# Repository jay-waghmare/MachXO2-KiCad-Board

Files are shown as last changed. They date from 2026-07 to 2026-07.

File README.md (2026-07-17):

# MachXO2-640HC FPGA Breakout Board - KiCad Design 🛠️

> Custom breakout board for Lattice **LCMXO2-640HC-6MG132I** - Designed in KiCad 9.0.3 - 8 Sheets Hierarchical - By Jay Waghmare






<p align="center">
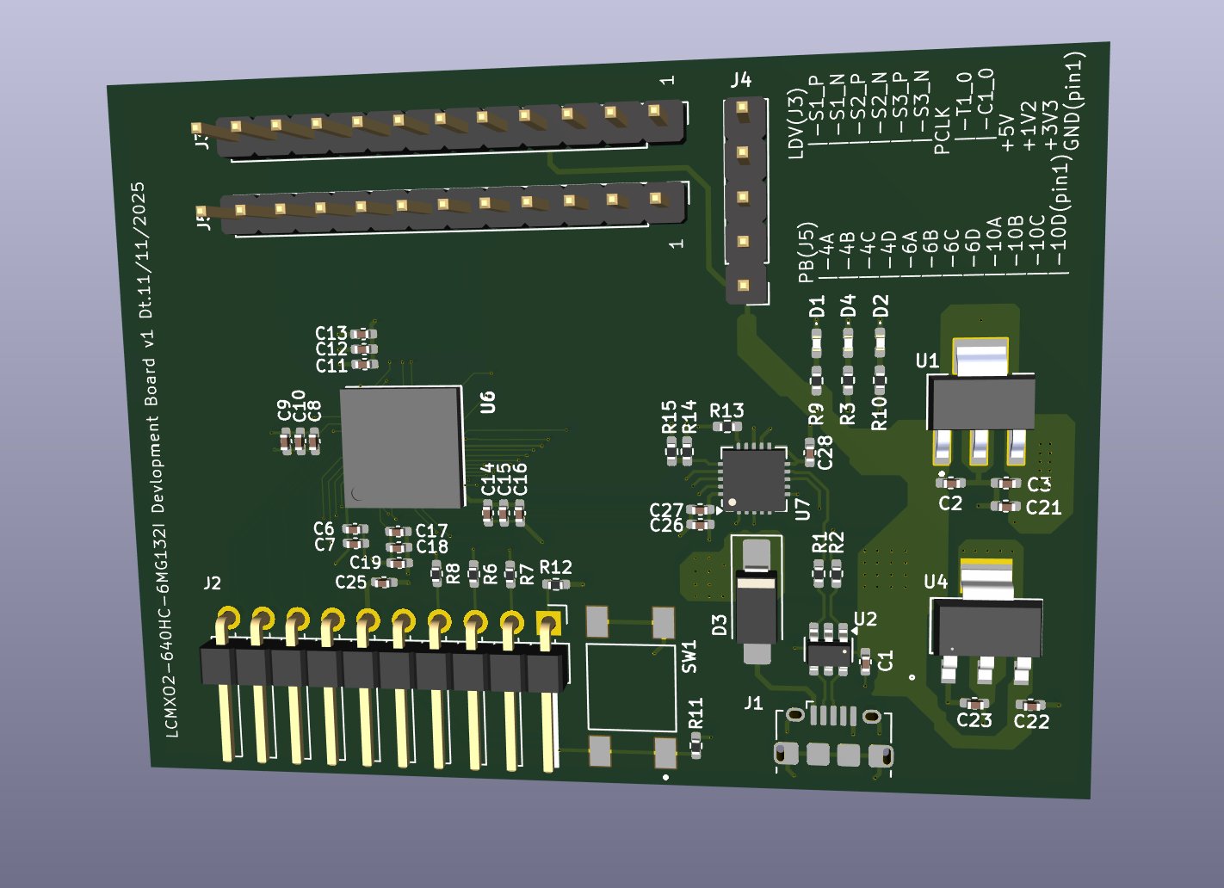
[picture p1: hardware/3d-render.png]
3D Render
  
  <br><em>3D Render - MachXO2-640HC Board (KiCad 3D View)</em>
</p>

## 🌟 What Is This? (From My Schematic PDF)

Custom FPGA development board designed from scratch in KiCad for **Lattice MachXO2 LCMXO2-640HC-6MG132I** (640 LUTs, 132-ball CSBGA).

**Full breakout board, not simple LED:**

- USB Mini-B (J1) for power + data with ESD protection USBLC6-2SC6 (U2)
- Dual LDO: 5V→3.3V TL1963A-33DCYR (U4) and 5V→1.2V LD1117S12CTR (U5) for core + I/O
- FT231XQ USB-UART bridge (U7) for serial
- JTAG header 1x10 (J2) for Lattice HW-USBN-2B programmer (10 flywires - White TCK, Orange TDI, Brown TDO, Purple TMS...)
- All 4 I/O Banks broken out: Bank0 Top (PT6A...), Bank1 Right (PR28... LVDS), Bank2/3 Left (PL2A...), Bank Bottom (PB4A...) + GND/NC
- Power LEDs D1 D2, User LEDs, Button SW1 for PROGRAMN

Why I made my own? To learn FPGA hardware - Power sequencing, decoupling, JTAG, I/O banks.

**8 Sheets Hierarchical (KiCad 9.0.3, file MACHXO2_test.kicad_sch):**

| Sheet | File | Content |
|---|---|---|
| 1/8 | MACHXO2_test.kicad_sch | Top Level - Power, User_IO/Banks, Device_Management blocks |
| 2/8 | Power.kicad_sch | Power: USB Mini, 3.3V/1.2V LDOs, FPGA VCC/VCCIO decoupling C6 0.1uF C7 4.7uF etc, VCCIO table |
| 3/8 | USER_IO_Bank_T | Bank0 Top - U6B LCMXO2 Bank0, JTAG TDO/TDI/TCK/TMS, J3 12-pin socket |
| 4/8 | USER_IO_Bank_R | Bank1 Right - U6C Bank1, LVDS1/2/3, PCLK, J4 10-pin header |
| 5/8 | USER_IO_Bank_L | Bank Left - U6D Bank Left PL2A...PL7B |
| 6/8 | USER_IO_Bank_B | Bank Bottom - U6E Bank Bottom PB4A...PB14B |
| 7/8 | USER_Config | Config - JTAG J2, PROGRAMN button SW1, FT231XQ UART, JTAG header flywire table |
| 8/8 | GND&NC | GND & NC - U6F/U6G NC pins and GND balls |

## ✨ Board Features (From Schematic)

- **FPGA:** U6 LCMXO2-640HC-6MG132I, 640 LUTs, MG132I, Speed 6
- **Power:** J1 USB Mini-B, D3 1N5819HW?, U2 USBLC6-2SC6 ESD, U4 TL1963A-33DCYR 5V→3.3V (C2 4.7uF, C3 10uF, C21 10uF), U5 LD1117S12CTR 5V→1.2V (C22 4.7uF, C23 10uF, C24 10uF), D1 D2 power LEDs with R8 1K, C6 0.1uF C7 4.7uF per +1V2, C8 0.1uF C10 1uF C9 4.7uF per +3V3 bank - Proper decoupling!
- **Recommended VCCIO (Your Table):** PB left 3.3V (sensors, SPI flash), PL lower 1.8V (low-voltage memory), PR right 1.8V/2.5V (high-speed), PT top 3.3V (UART, SPI, USB-UART)
- **JTAG:** J2 1x10 header, R6 R7 R8 22R series for TDO/TDI/TCK/TMS, R11 4K7 pull-up for PROGRAMN, SW1 dual push button, Notes: INITN B13 open-drain float OK, JTAGENB B9 float OK (internal weak pull-up)
- **UART:** U7 FT231XQ with C26 4.7uF C27 0.1uF C28 0.1uF, TXD_FTDI, RXD_FTDI, RTS_FTDI, CTS, VBUS detection R1 4K7 + R13 10K divider
- **JTAG Programmer:** Lattice HW-USBN-2B USB cable with 10 flywire - Official tool - TCK White 4.7K to GND, TDI Orange 22R series, TDO Brown direct, TMS Purple 22R series, GND Black, VCC Red 0.1uF, PROGRAMN Yellow 4.7K+btn, DONE Blue LED+330Ω, INITN Green float, JTAGENB Gray float

## 📁 Files (Your Actual Uploads - Live)

**You uploaded:** .kicad_pro, .kicad_sch, .kicad_pcb, .kicad_prl, schematic.pdf, 3d-render.png, pcb_preview.png - Full project!

## 📸 Photos / Renders

| Schematic PDF | PCB Preview | 3D Render |
|---|---|---|
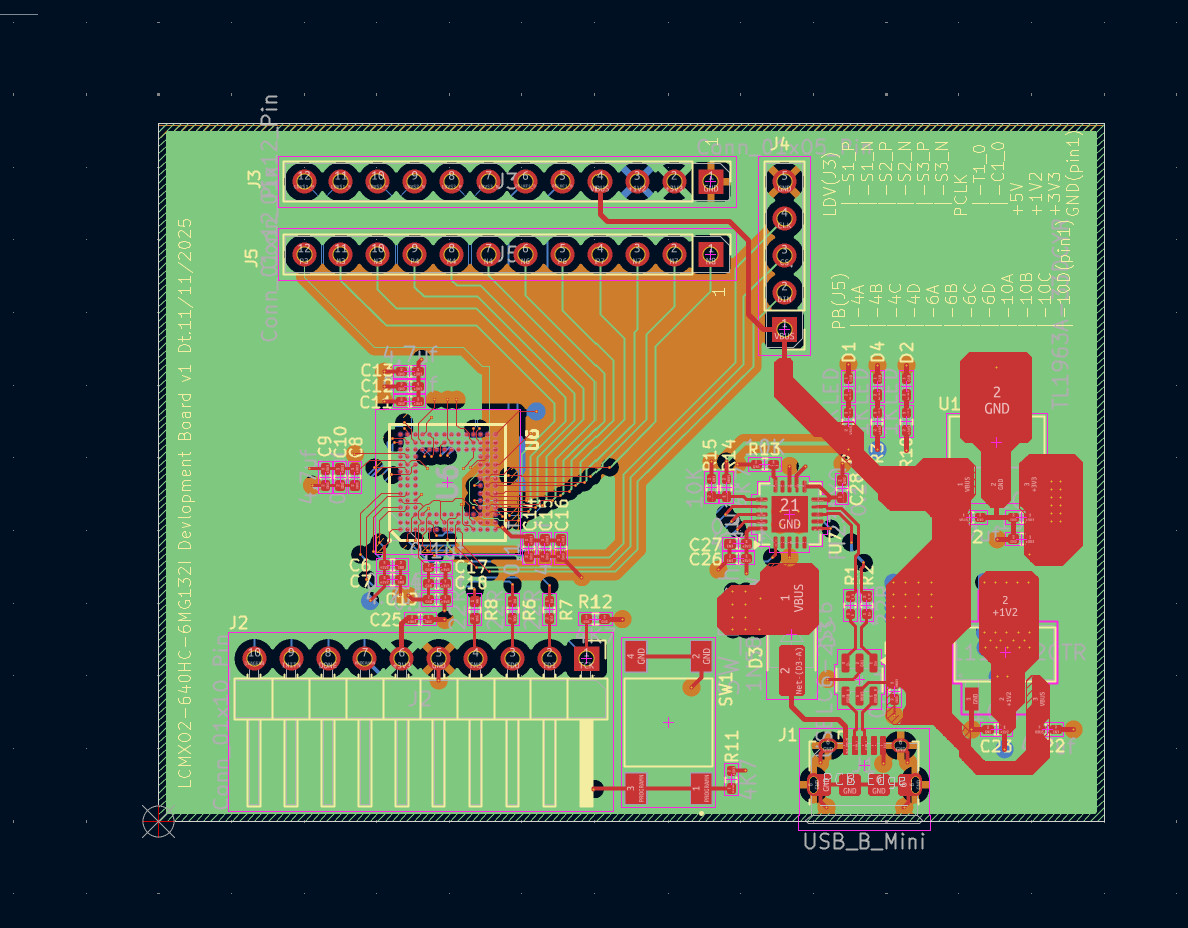
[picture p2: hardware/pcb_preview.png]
| [schematic.pdf](hardware/schematics/schematic.pdf) (8 pages) |  |  |

<p align="center">
  PCB Preview
  3D Render
</p>

## 📦 How to View

1. Install KiCad 9.0.3: https://kicad.org/download/
2. Clone: git clone https://github.com/jay-waghmare/MachXO2-KiCad-Board.git
cd MachXO2-KiCad-Board
3. Open `MACHXO2_test.kicad_pro` → Schematic Editor (8 sheets) → PCB Editor → 3D View

## 🗺️ Roadmap

- [x] KiCad hierarchical schematic 8 sheets - LCMXO2-640HC - Done (your PDF)
- [x] Upload .kicad_pro, .kicad_sch, .kicad_pcb, .kicad_prl - Done (5-6 greens today!)
- [x] Upload schematic.pdf + 3D renders - Done 5 mins ago!
- [ ] Add hardware/bom.md with exact values from schematic
- [ ] Add docs/design.md - Why 640HC, why TL1963A + LD1117, why 132-ball
- [ ] Export Gerbers: File → Fabrication Outputs → Gerbers → hardware/pcb/gerbers.zip
- [ ] Fabricate at JLCPCB
- [ ] Bring-up: Power test 3.3V/1.2V, JTAG scan with HW-USBN-2B, first blinky
- [ ] Add real board photos

## 👨‍💻 Author

**Jay Waghmare** - FPGA 
- GitHub: [@jay-waghmare](https://github.com/jay-waghmare) 
- Board: LCMXO2-640HC-6MG132I custom breakout - Designed from scratch in KiCad 9.0.3

If you like FPGA hardware boards, please ⭐ star!

## 📄 License

MIT License

> Designed from scratch in KiCad 9.0.3

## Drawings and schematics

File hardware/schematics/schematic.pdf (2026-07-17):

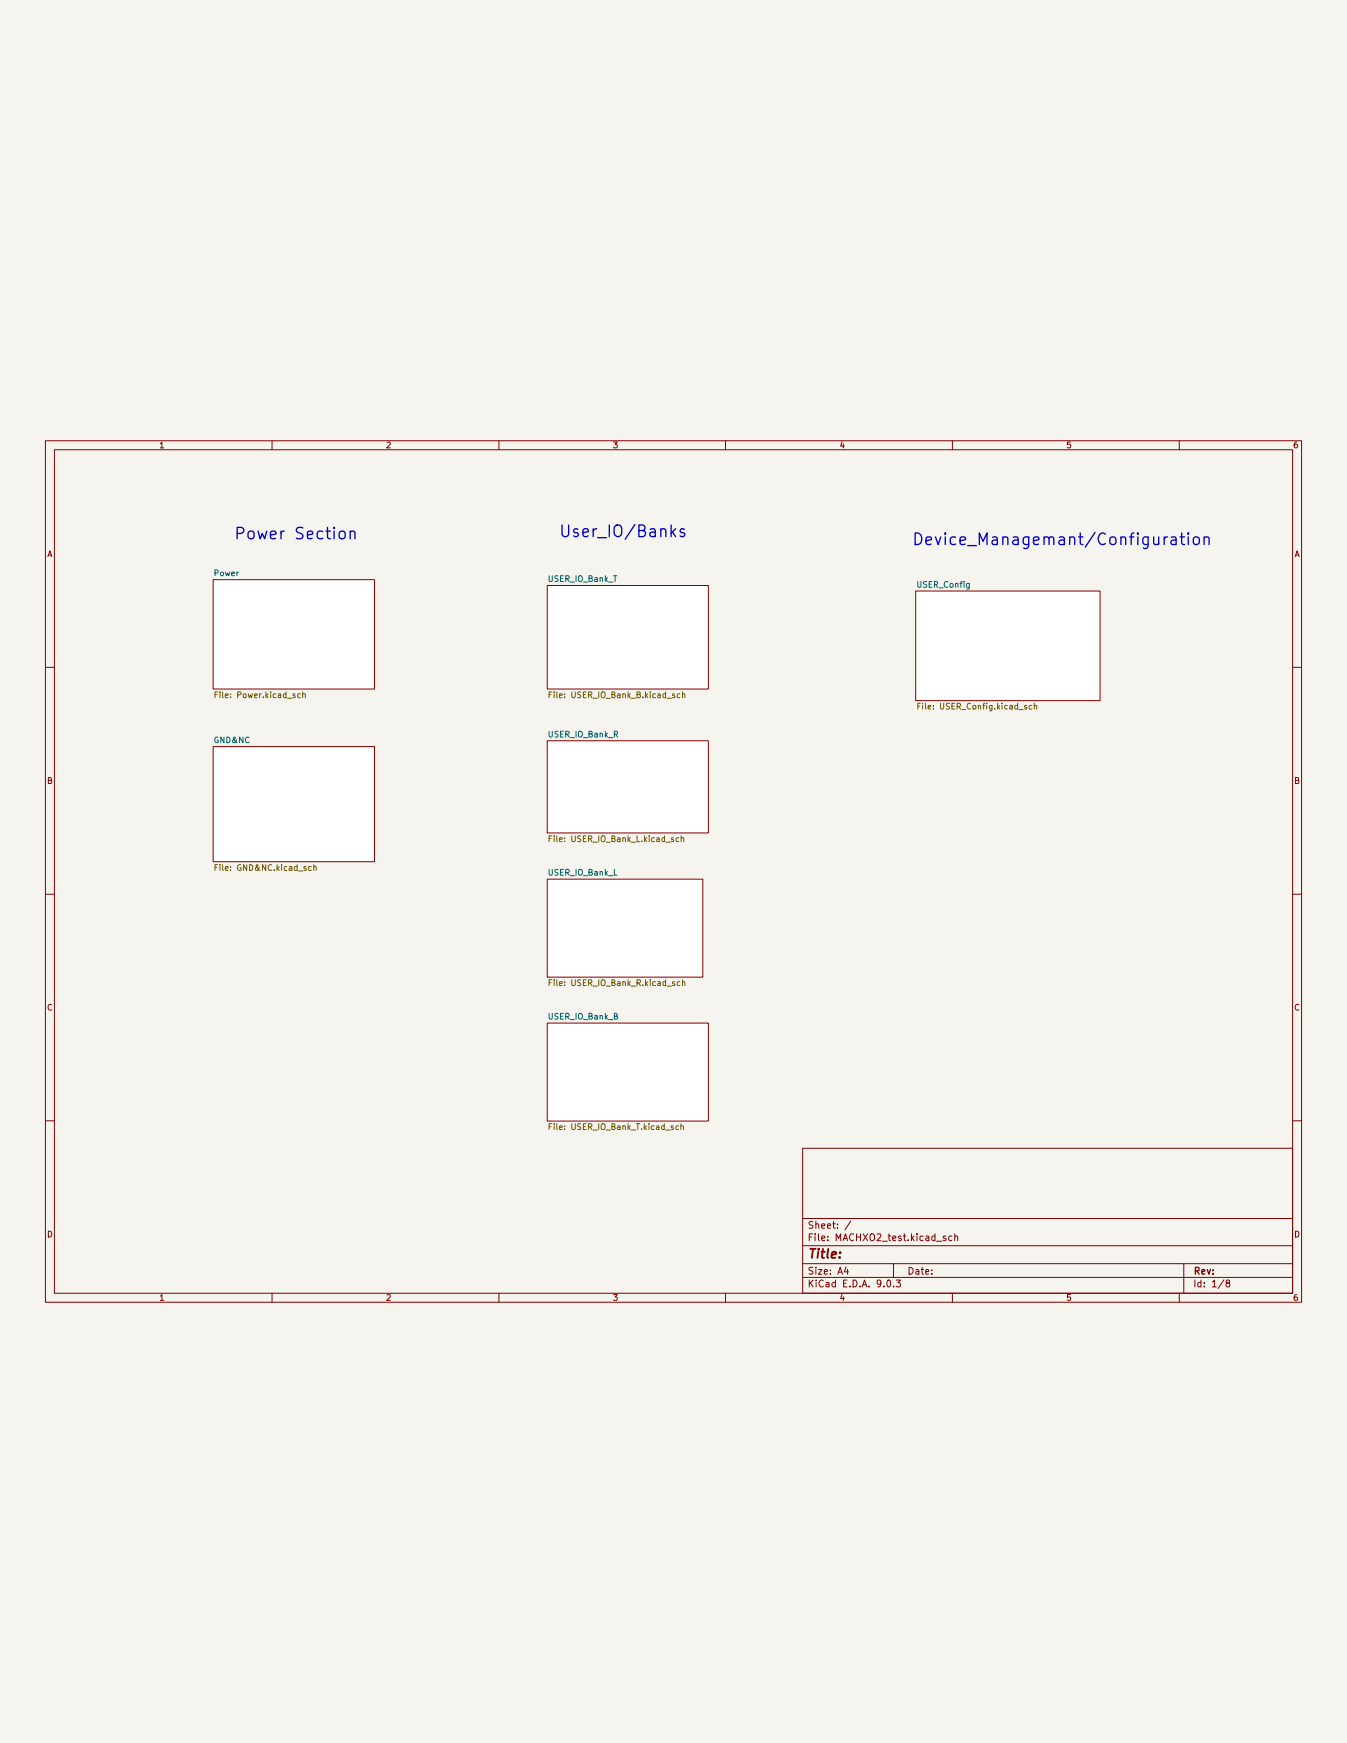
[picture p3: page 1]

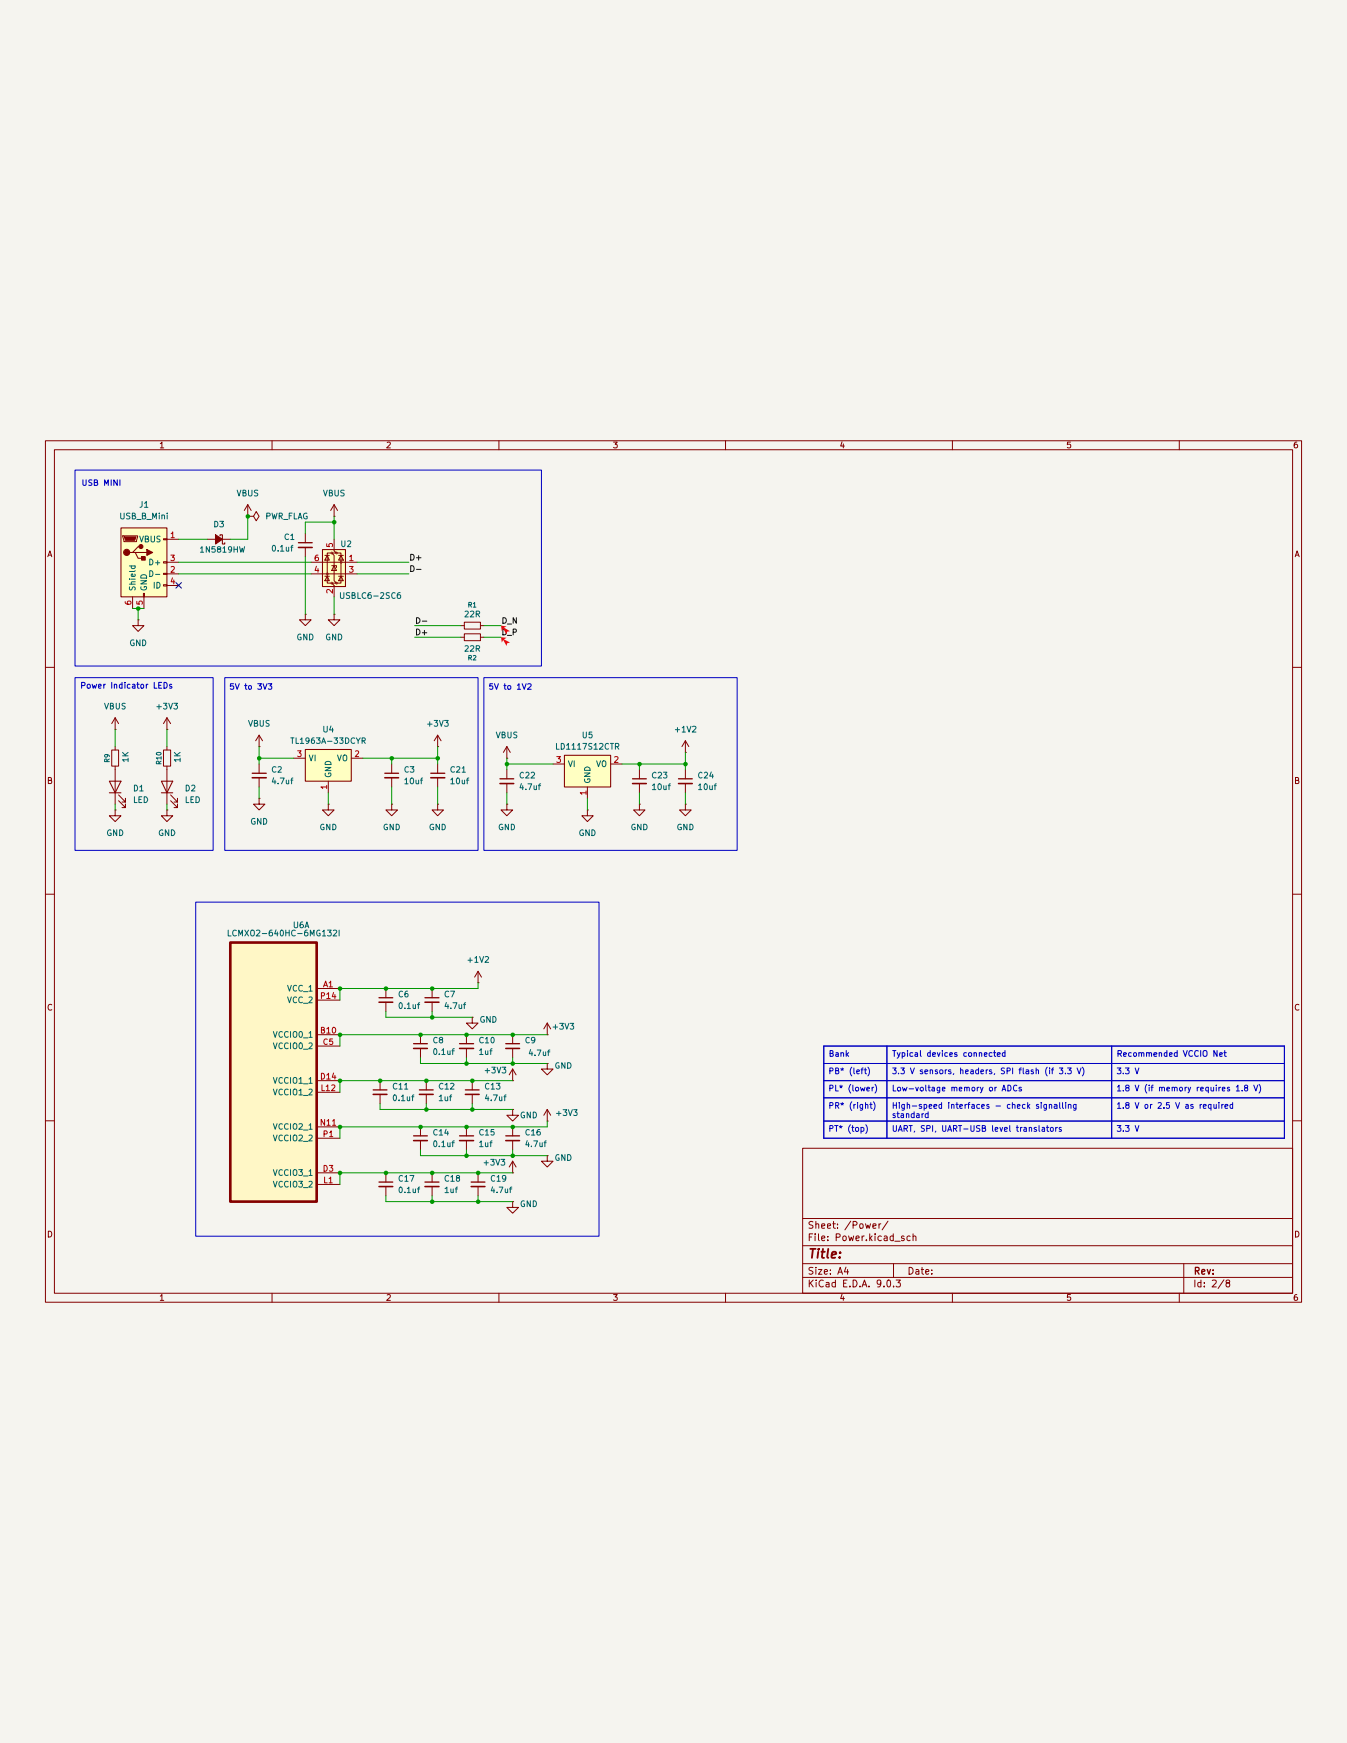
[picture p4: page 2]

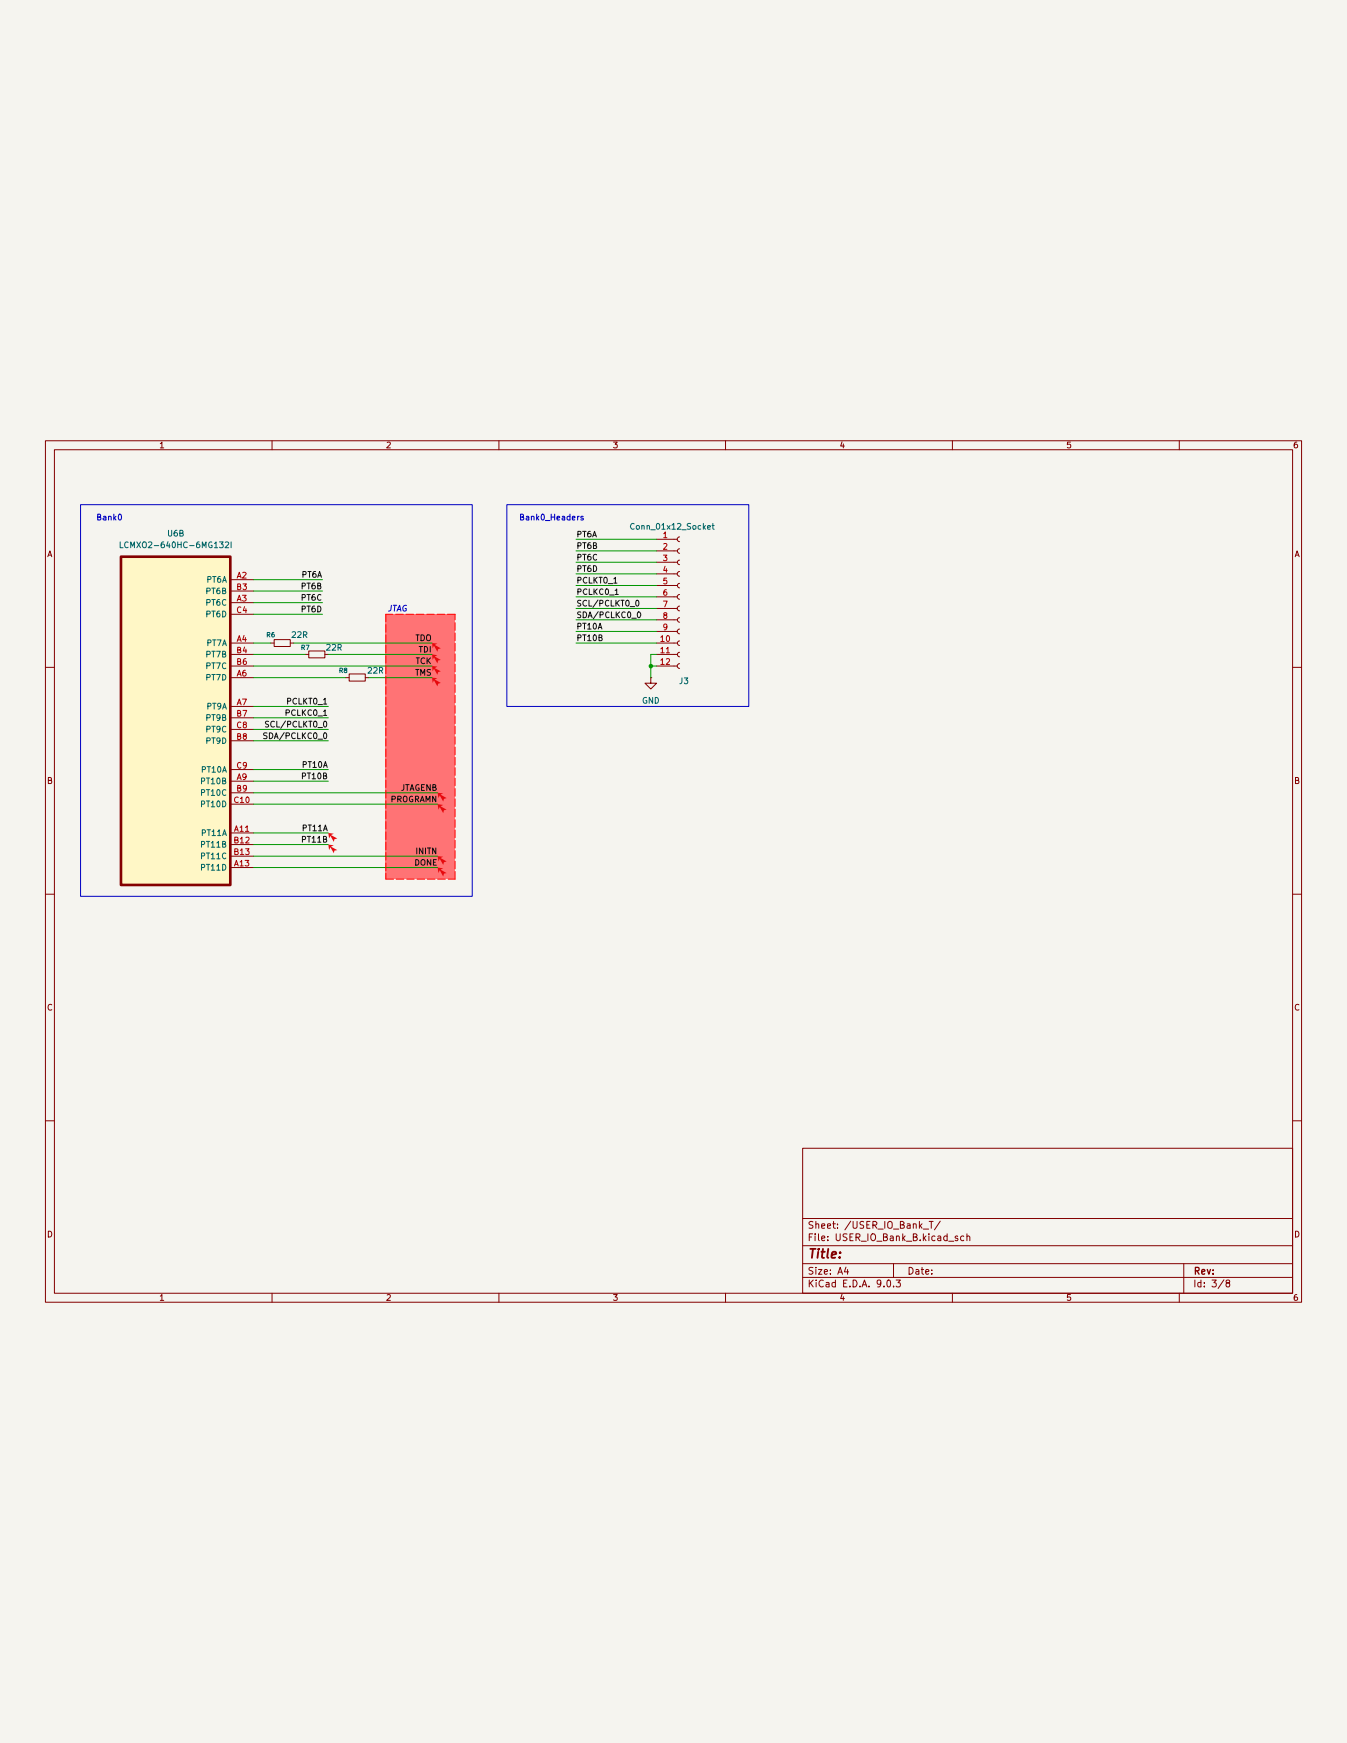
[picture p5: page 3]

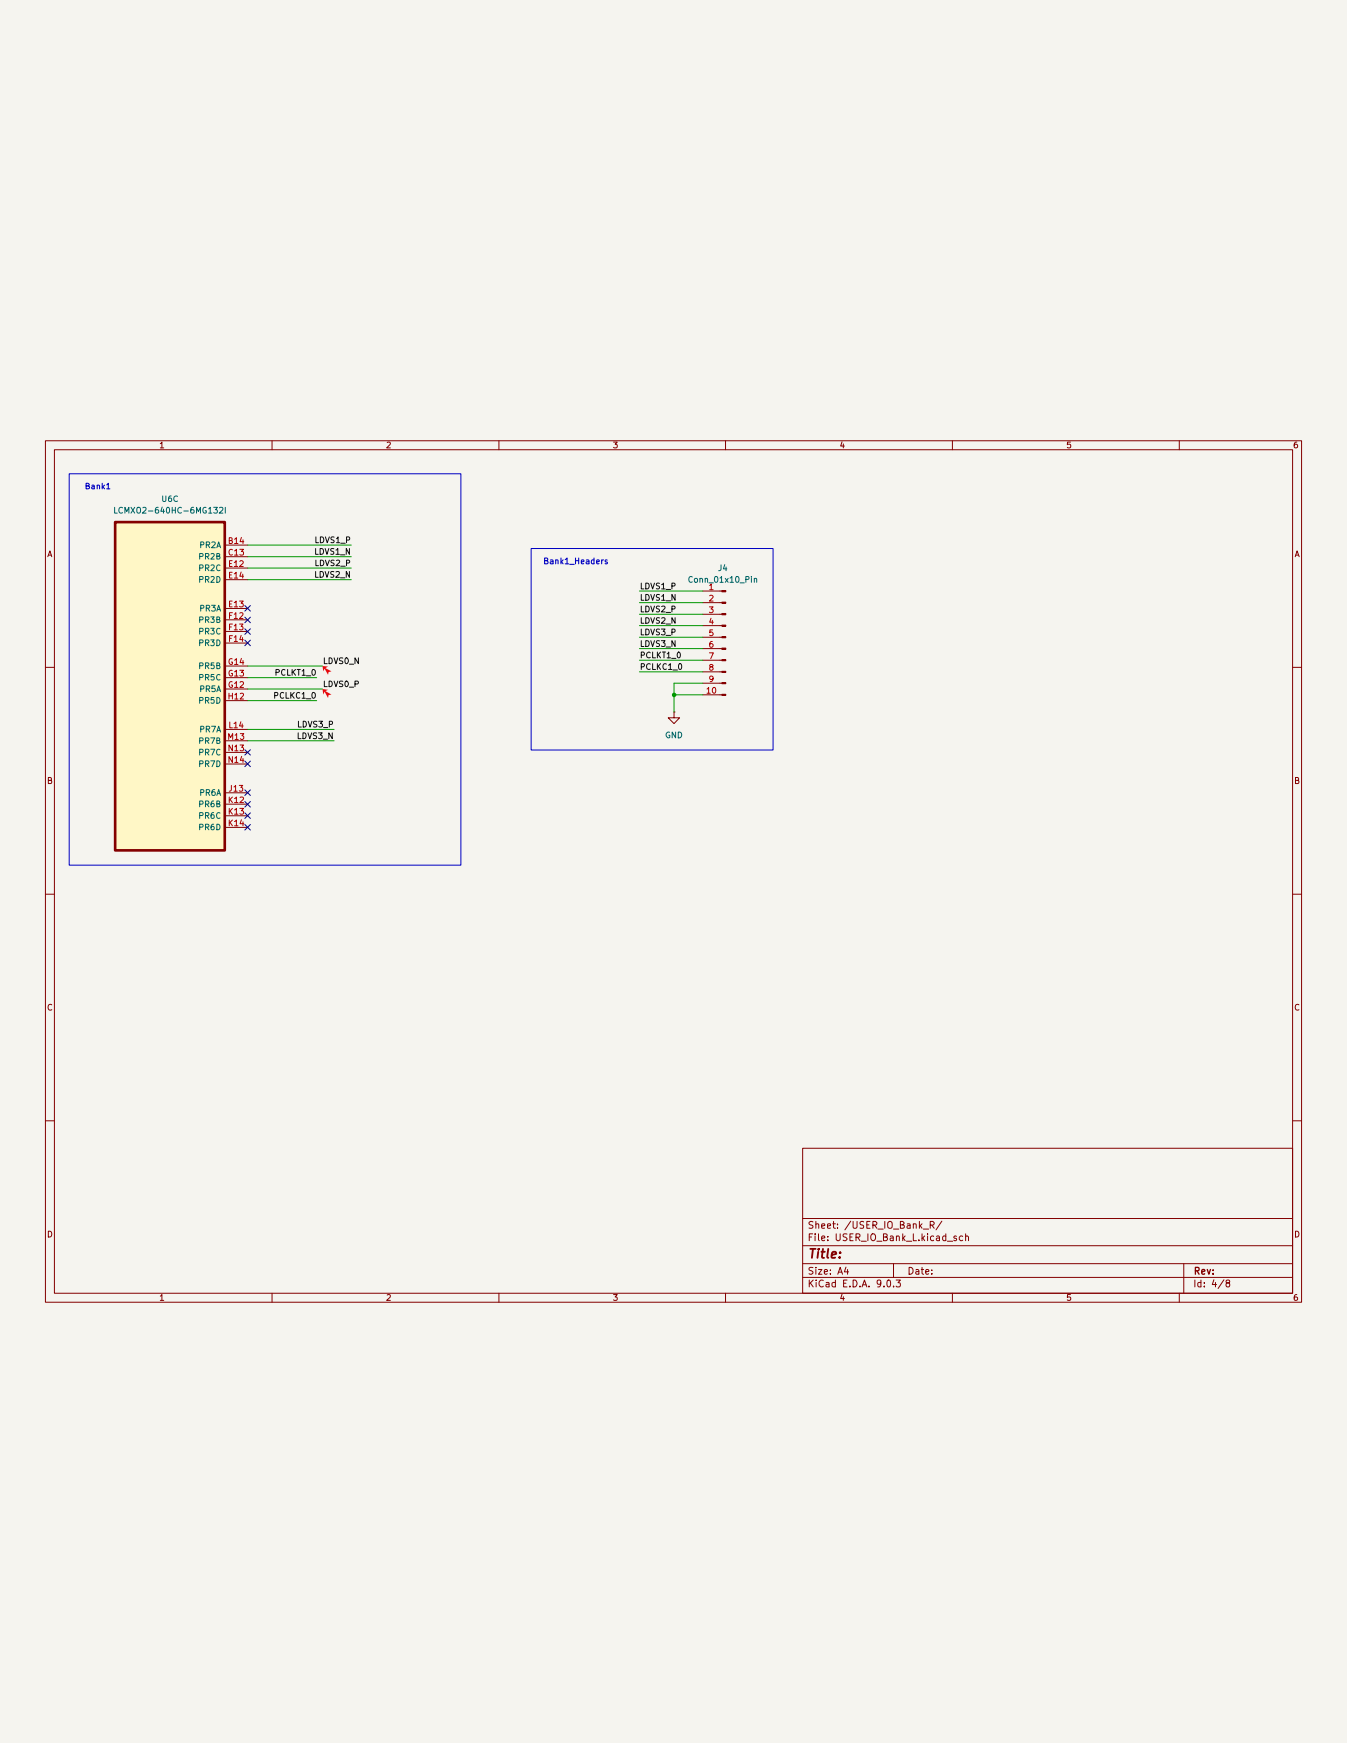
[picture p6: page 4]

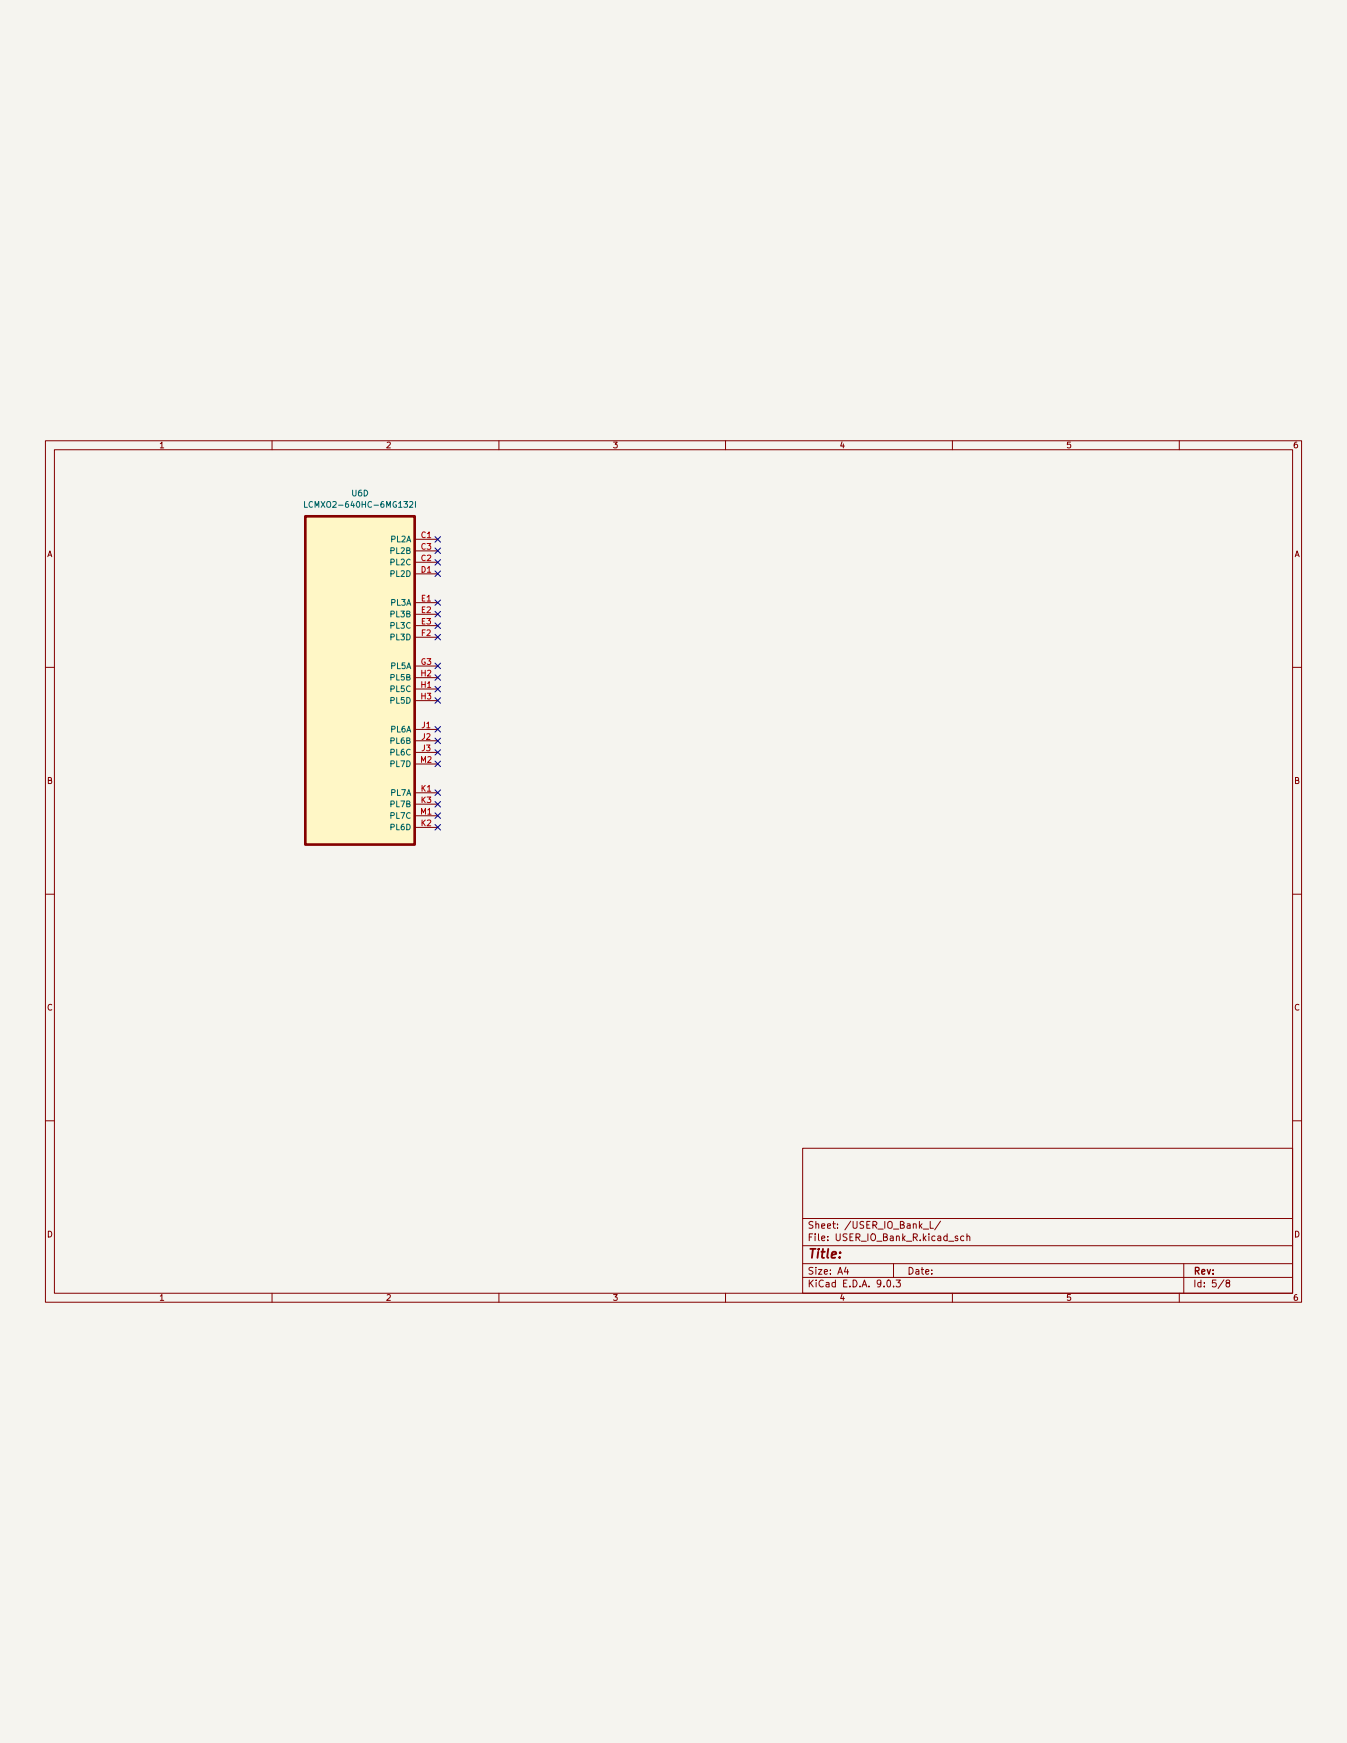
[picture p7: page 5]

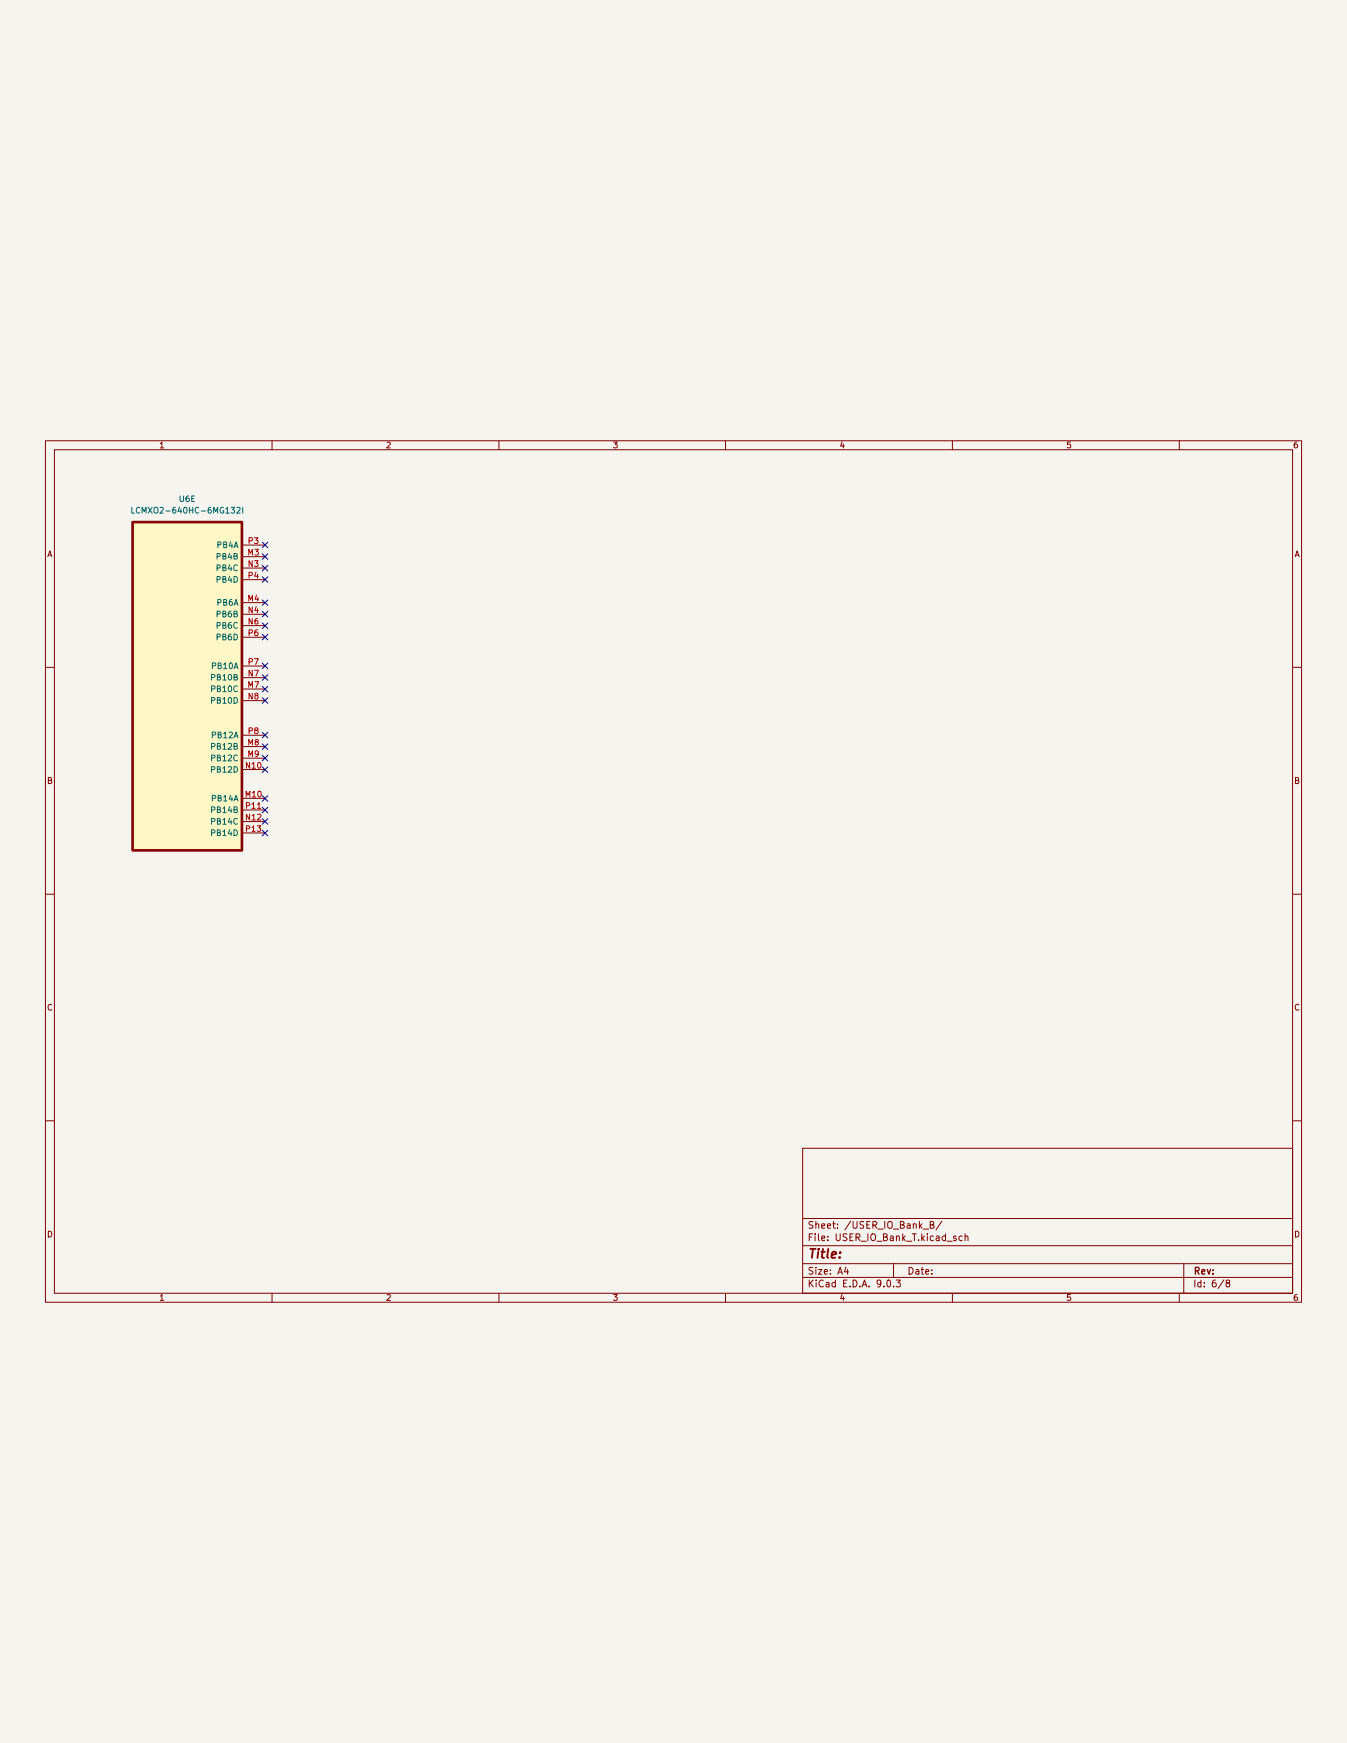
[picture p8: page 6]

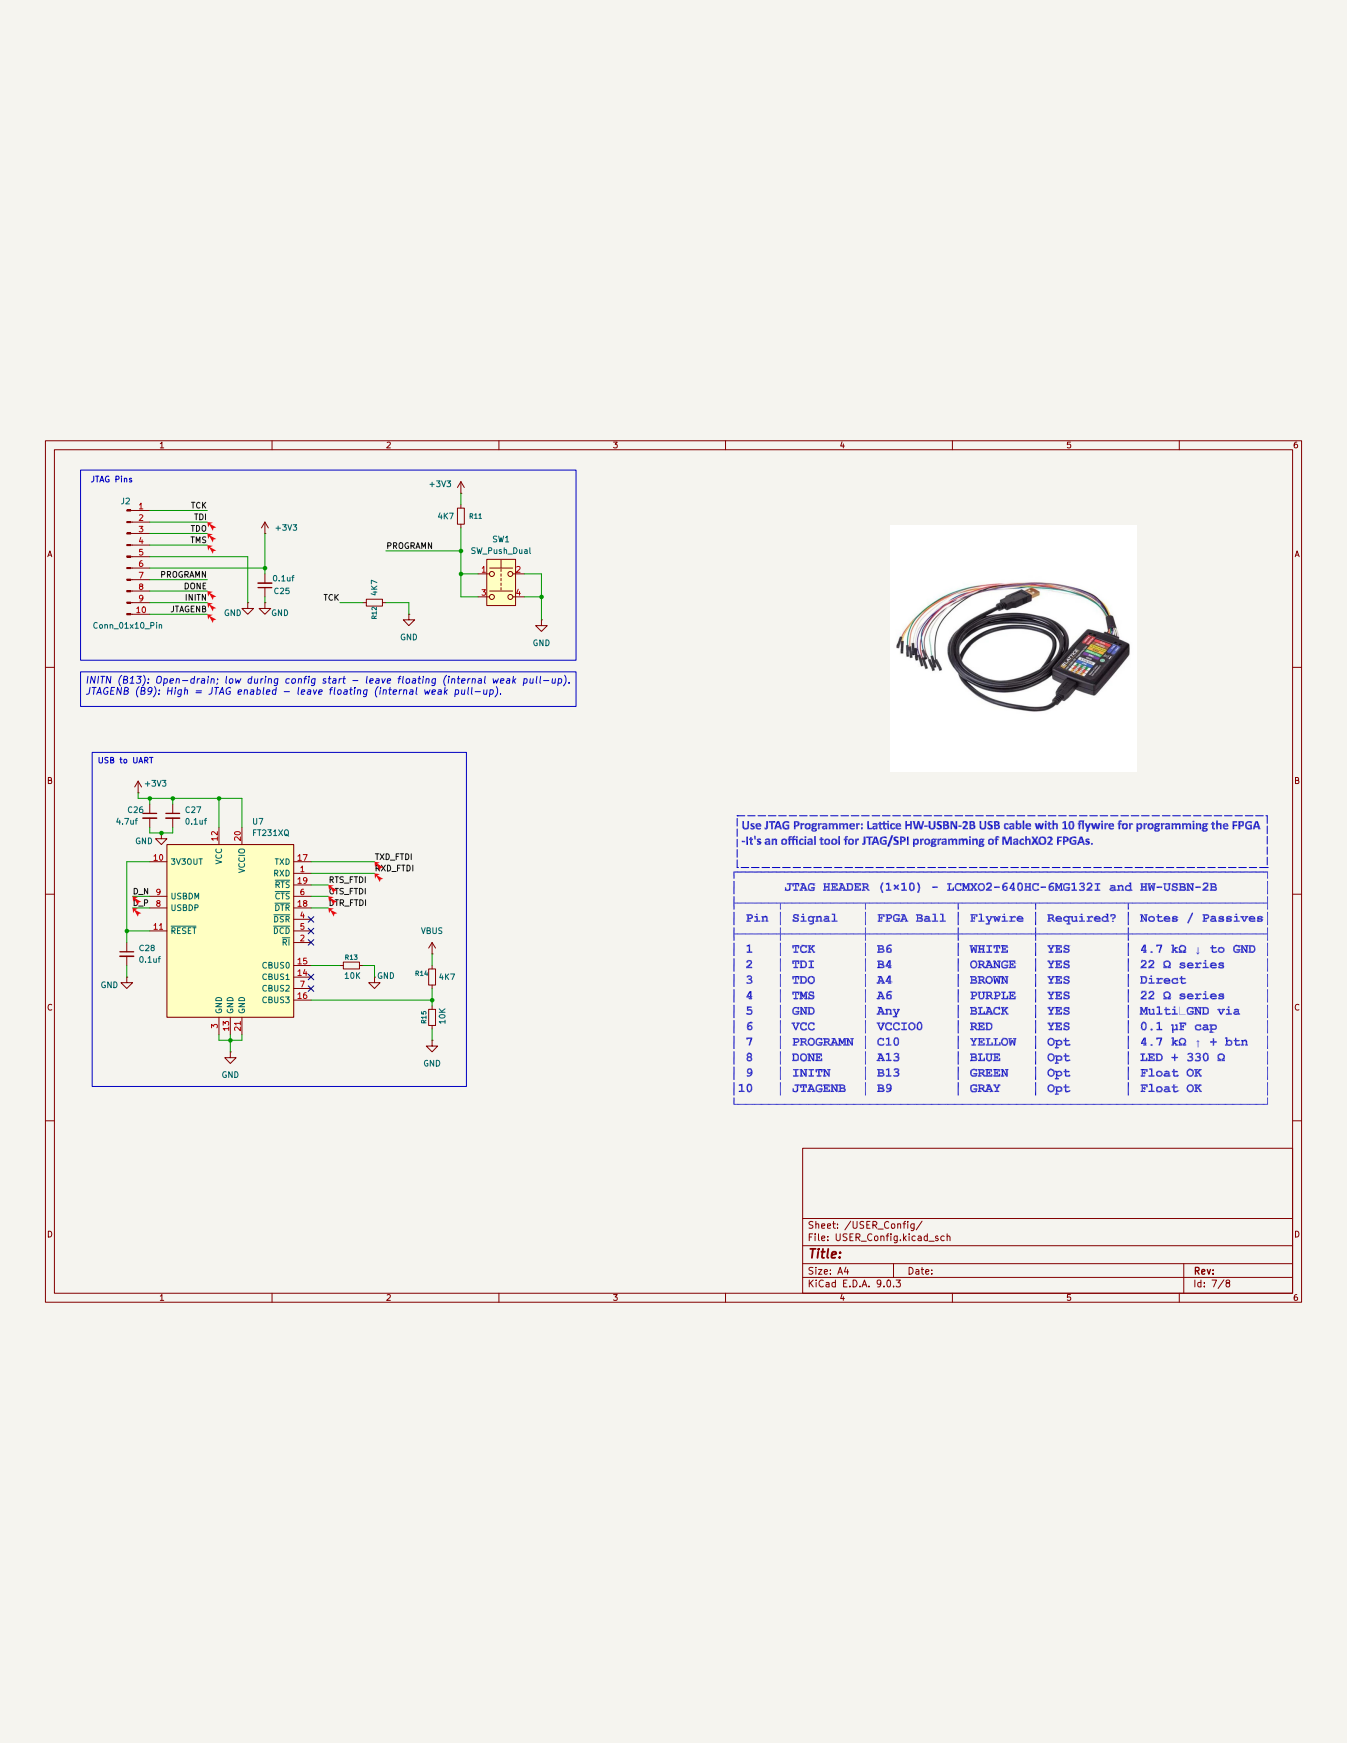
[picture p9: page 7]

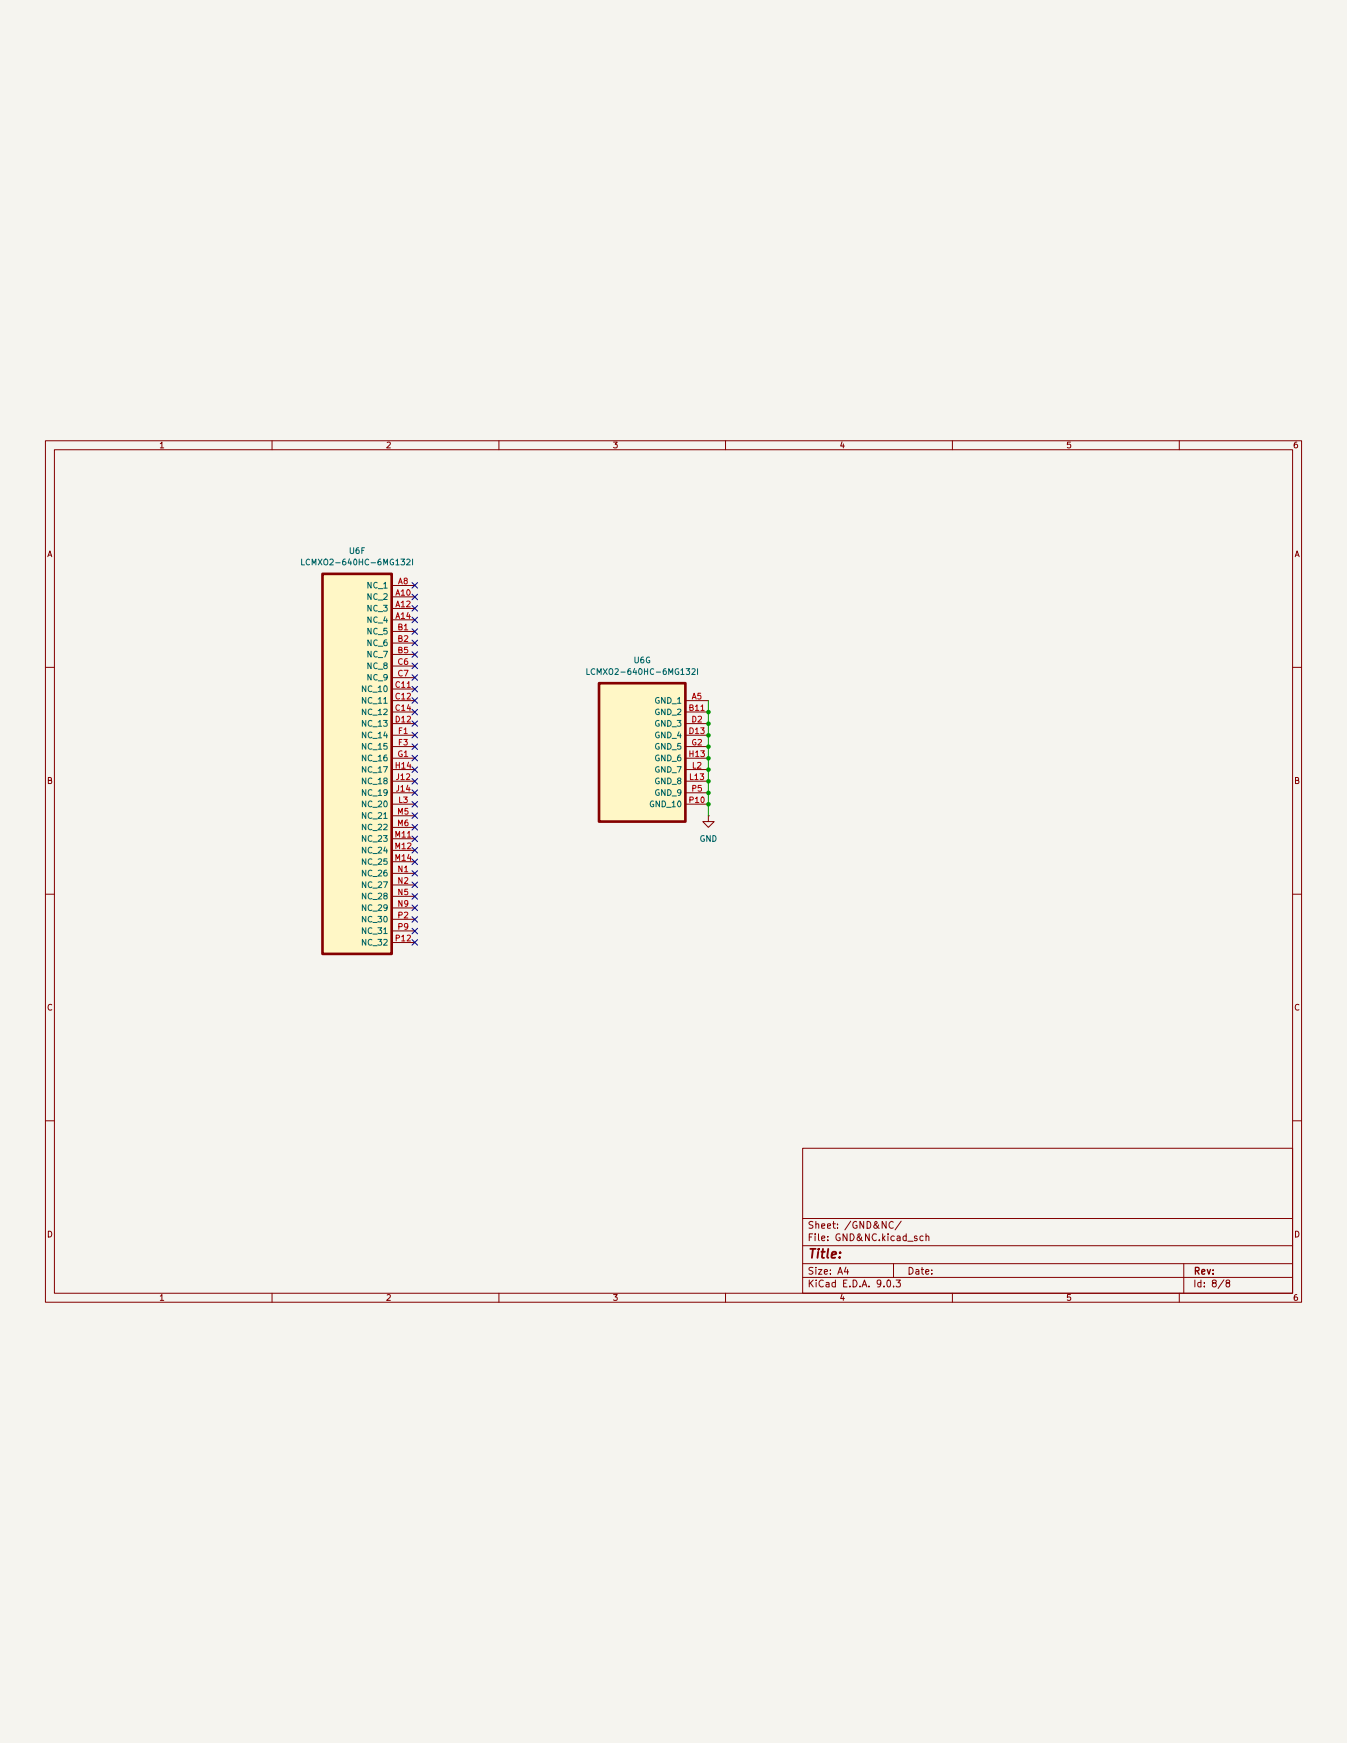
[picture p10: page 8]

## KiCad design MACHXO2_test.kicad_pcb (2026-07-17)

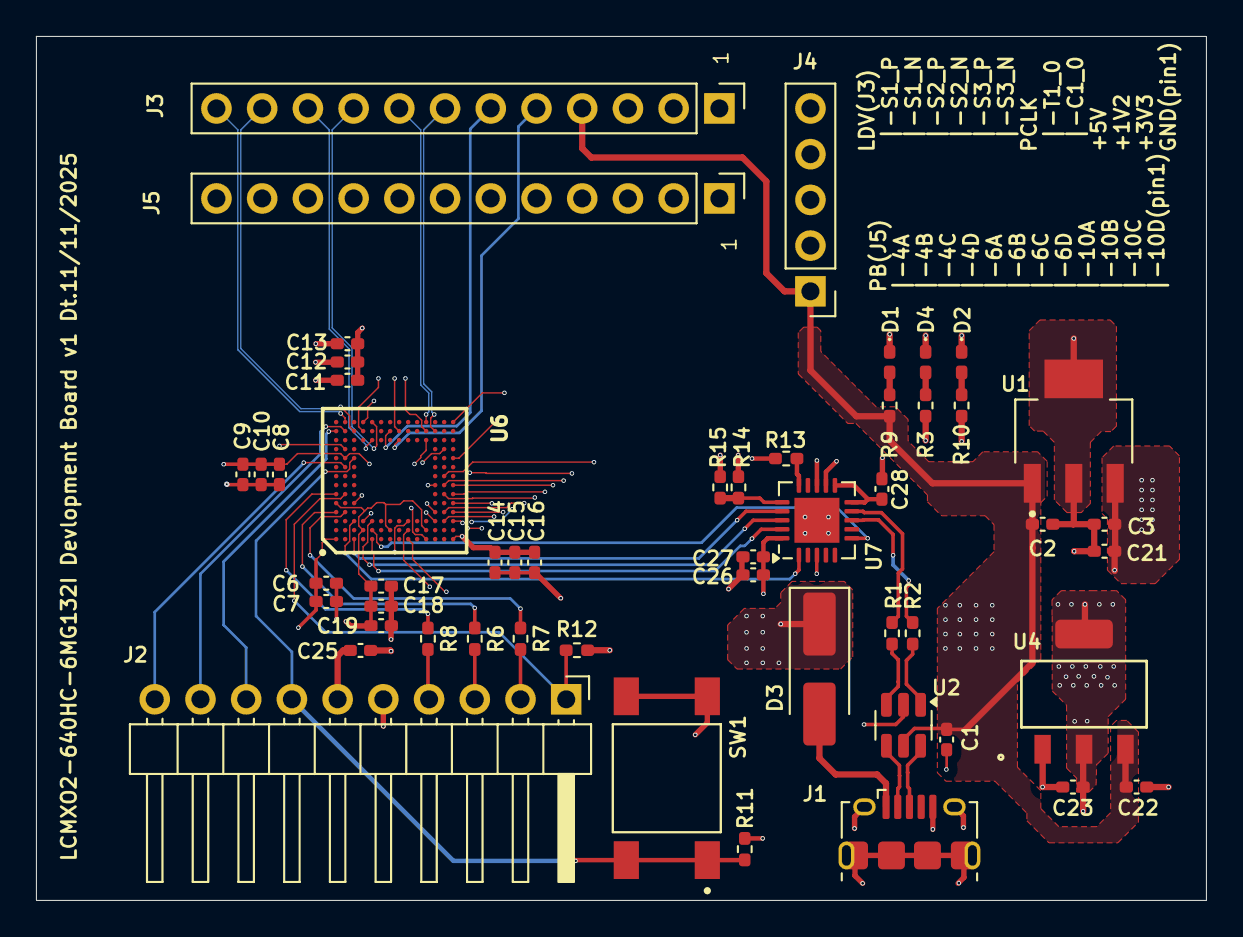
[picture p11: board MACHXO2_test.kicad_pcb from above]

Board: 4 copper layers, 65.0 x 48.0 mm, 52 parts (0 on the bottom side), 56 nets.

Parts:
C1, C6, C8, C11, C14, C17, C25, C27, C28: 0.1uf; C_0402_1005Metric_Pad0.74x0.62mm_HandSolder
C2, C7, C9, C13, C16, C19, C22, C26: 4.7uf; C_0402_1005Metric_Pad0.74x0.62mm_HandSolder
C3, C21, C23: 10uf; C_0402_1005Metric_Pad0.74x0.62mm_HandSolder
C10, C12, C15, C18: 1uf; C_0402_1005Metric_Pad0.74x0.62mm_HandSolder
D1, D2, D4: LED; LED_0402_1005Metric_Pad0.77x0.64mm_HandSolder
D3: 1N5819HW; D_SMA_Handsoldering
J1: USB_B_Mini; USB_Micro-B_Amphenol_10118194-0001LF_Horizontal
J2: Conn_01x10_Pin; PinHeader_1x10_P2.54mm_Horizontal
J3, J5: Conn_01x12_Pin; PinHeader_1x12_P2.54mm_Vertical
J4: Conn_01x05_Pin; PinHeader_1x05_P2.54mm_Vertical
R1, R2, R6, R7, R8: 22R; R_0402_1005Metric_Pad0.72x0.64mm_HandSolder
R3, R9, R10: 1K; R_0402_1005Metric_Pad0.72x0.64mm_HandSolder
R11, R12, R14: 4K7; R_0402_1005Metric_Pad0.72x0.64mm_HandSolder
R13, R15: 10K; R_0402_1005Metric_Pad0.72x0.64mm_HandSolder
SW1: SW_Push_Dual; SW_TL3301AF160QG
U1: TL1963A-33DCYR; VREG_TL1963A-33DCYR
U2: USBLC6-2SC6; SOT-23-6
U4: LD1117S12CTR; SOT-223_STM
U6: LCMXO2-640HC-6MG132I; BGA132C50P14X14_800X800X135
U7: FT231XQ; QFN-20-1EP_4x4mm_P0.5mm_EP2.5x2.5mm

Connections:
+1V2: C6.1, C7.1, C23.1, J3.3, R3.2, U4.2 (VOUT), U6.A1 (VCC_1), U6.P14 (VCC_2)
+3V3: C3.1, C8.1, C9.1, C10.1, C11.1, C12.1, C13.1, C14.1, C15.1, C16.1, C17.1, C18.1, C19.1, C21.1, C25.2, C26.1, C27.1, J2.6, J3.2, R10.2, R11.2, U1.3 (OUT), U6.B10 (VCCIO0_1), U6.C5 (VCCIO0_2), U6.D3 (VCCIO3_1), U6.D14 (VCCIO1_1), U6.L1 (VCCIO3_2), U6.L12 (VCCIO1_2), U6.N11 (VCCIO2_1), U6.P1 (VCCIO2_2), U7.12 (VCC), U7.20 (VCCIO)
/Power/D+: R2.1, U2.1 (I/O1)
/Power/D-: R1.1, U2.3 (I/O2)
/Power/USBD_N: J1.2 (D-), U2.4 (I/O2)
/Power/USBD_P: J1.3 (D+), U2.6 (I/O1)
/USER_IO_Bank_R/LDVS1_N: J3.11, U6.C13 (PR2B)
/USER_IO_Bank_R/LDVS1_P: J3.12, U6.B14 (PR2A)
/USER_IO_Bank_R/LDVS2_N: J3.9, U6.E14 (PR2D)
/USER_IO_Bank_R/LDVS2_P: J3.10, U6.E12 (PR2C)
/USER_IO_Bank_R/LDVS3_N: J3.7, U6.M13 (PR7B)
/USER_IO_Bank_R/LDVS3_P: J3.8, U6.L14 (PR7A)
/USER_IO_Bank_R/PCLKC1_0: J3.5, U6.H12 (PR5D)
/USER_IO_Bank_R/PCLKT1_0: J3.6, U6.G13 (PR5C)
A4: R6.1, U6.A4 (PT7A)
A6: R8.1, U6.A6 (PT7D)
B4: R7.1, U6.B4 (PT7B)
CLK: J4.4, U6.J3 (PL6C)
CS: J4.3, U6.J2 (PL6B)
CTS_FTDI: U6.E2 (PL3B), U7.6 (~CTS)
DIN: J4.2, U6.J1 (PL6A)
DONE: J2.8, U6.A13 (PT11D)
DTR_FTDI: U6.E3 (PL3C), U7.18 (~DTR)
D_N: R1.2, U7.9 (USBDM)
D_P: R2.2, U7.8 (USBDP)
GND: C1.2, C2.2, C3.2, C6.2, C7.2, C8.2, C9.2, C10.2, C11.2, C12.2, C13.2, C14.2, C15.2, C16.2, C17.2, C18.2, C19.2, C21.2, C22.2, C23.2, C25.1, C26.2, C27.2, C28.2, D1.1 (K), D2.1 (K), D4.1 (K), J1.5 (GND), J1.6 (Shield), J2.5, J3.1, J4.5, R12.2, R13.2, R15.1, SW1.2, SW1.4, U1.2 (GND), U2.2 (GND), U4.1 (GND), U6.A5 (GND_1), U6.B11 (GND_2), U6.D2 (GND_3), U6.D13 (GND_4), U6.G2 (GND_5), U6.H13 (GND_6), U6.L2 (GND_7), U6.L13 (GND_8), U6.P5 (GND_9), U6.P10 (GND_10), U7.3 (GND), U7.13 (GND), U7.21 (GND)
INITN: J2.9, U6.B13 (PT11C)
JTAGENB: J2.10, U6.B9 (PT10C)
M3: J5.11, U6.M3 (PB4B)
M4: J5.8, U6.M4 (PB6A)
M7: J5.2, U6.M7 (PB10C)
N3: J5.10, U6.N3 (PB4C)
N4: J5.7, U6.N4 (PB6B)
N6: J5.6, U6.N6 (PB6C)
N7: J5.3, U6.N7 (PB10B)
N8: J5.1, U6.N8 (PB10D)
unnamed: D1.2 (A), R9.1
unnamed: D2.2 (A), R10.1
unnamed: D3.2 (A), J1.1 (VBUS)
unnamed: D4.2 (A), R3.1
unnamed: C28.1, U7.10 (3V3OUT), U7.11 (~RESET)
unnamed: R13.1, U7.15 (CBUS0)
unnamed: R14.1, R15.2, U7.16 (CBUS3)
P3: J5.12, U6.P3 (PB4A)
P4: J5.9, U6.P4 (PB4D)
P6: J5.5, U6.P6 (PB6D)
P7: J5.4, U6.P7 (PB10A)
PROGRAMN: J2.7, R11.1, SW1.1, SW1.3, U6.C10 (PT10D)
RTS_FTDI: U6.E1 (PL3A), U7.19 (~RTS)
RXD_FTDI: U6.C3 (PL2B), U7.1 (RXD)
TCK: J2.1, R12.1, U6.B6 (PT7C)
TDI: J2.2, R7.2
TDO: J2.3, R6.2
TMS: J2.4, R8.2
TXD_FTDI: U6.C1 (PL2A), U7.17 (TXD)
VBUS: C1.1, C2.1, C22.1, D3.1 (K), J3.4, J4.1, R9.2, R14.2, U1.1 (IN), U2.5 (VBUS), U4.3 (VIN)

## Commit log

2026-07-17 Revise README for MachXO2 FPGA Board project
    Updated README to enhance project description and features.
2026-07-17 Revise README for MachXO2-640HC FPGA Breakout Board
    Updated README to reflect new FPGA model and KiCad version, added detailed board features and file structure.
2026-07-17 Update README with hardware connection details
    Added details about JTAG, UART, and JTAG Programmer connections.
